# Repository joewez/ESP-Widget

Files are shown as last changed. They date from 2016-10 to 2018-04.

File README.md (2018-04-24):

# ESP Widget

The "widget" is a device based on a Wemos D1 Mini (ESP8266).  It consists of...

    - A Wemos D1 Mini WiFi Microcontroller Board
    - A SSD1306 128x64 OLED Display (White)
    - A single WS2812/Neopixel Color LED
    - A small piezo-electric buzzer
    - Three (3) tactile input buttons

It uses MicroPython to control Wifi setup and operation of the device.

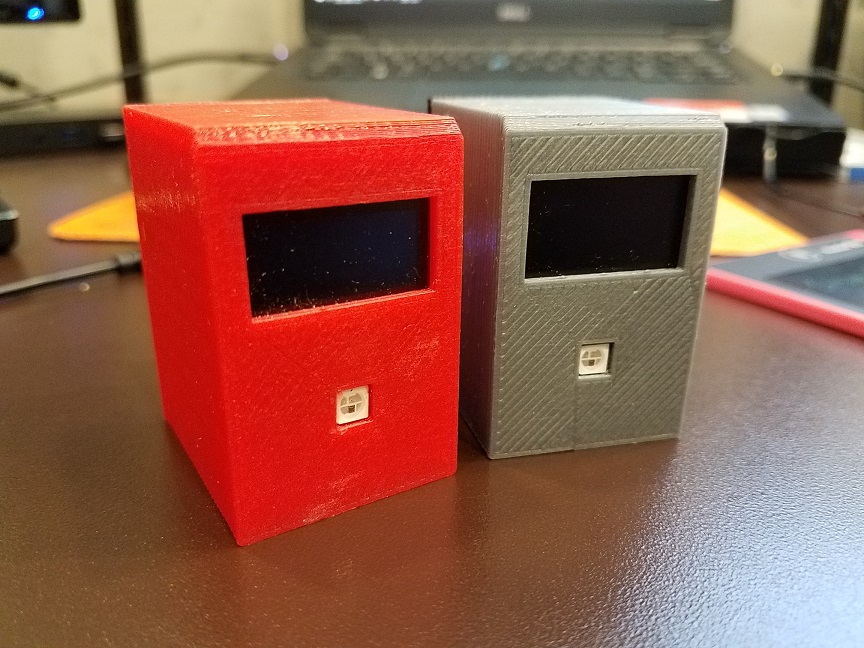
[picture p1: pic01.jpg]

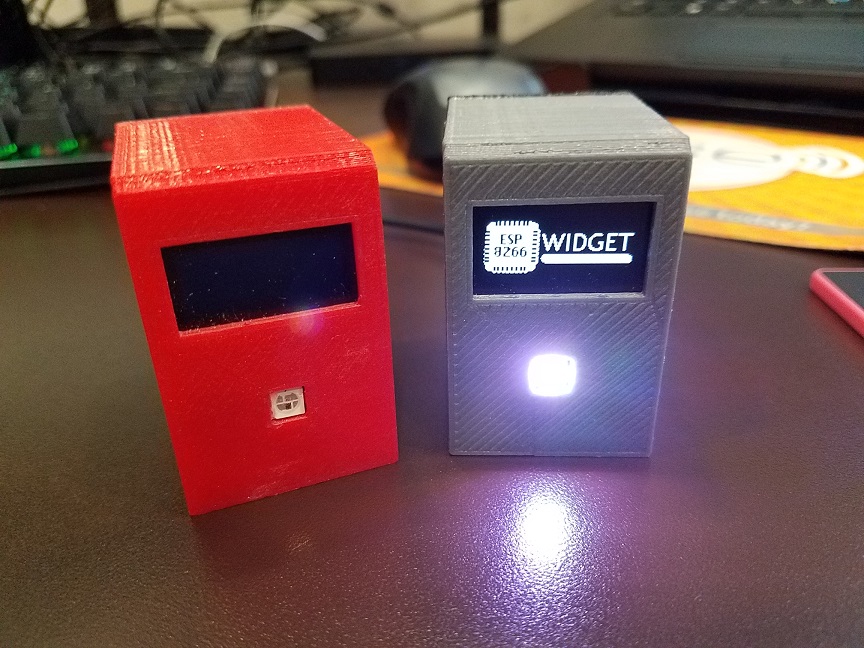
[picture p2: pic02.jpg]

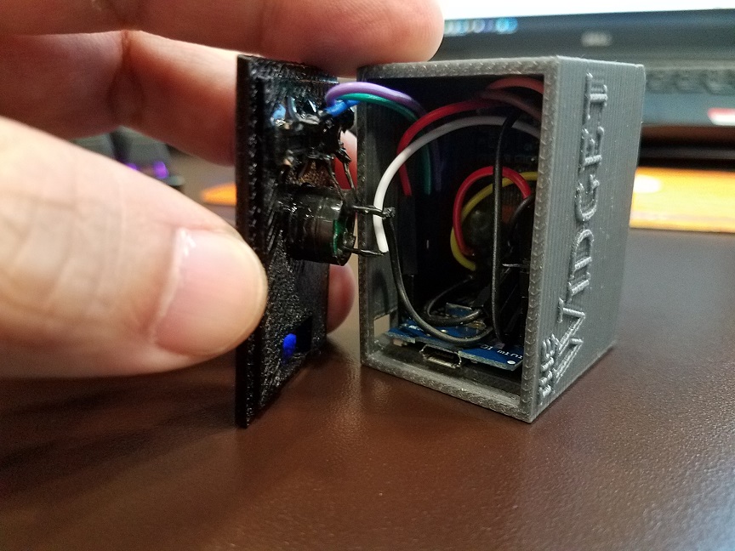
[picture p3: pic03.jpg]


The purpose of the device is to read a constantly updating document from the network and execute
the commands contained within.  The command allow you to...

    - Display text on the OLED
    - Change the color of the neopixel
    - Play a tone
    - etc...

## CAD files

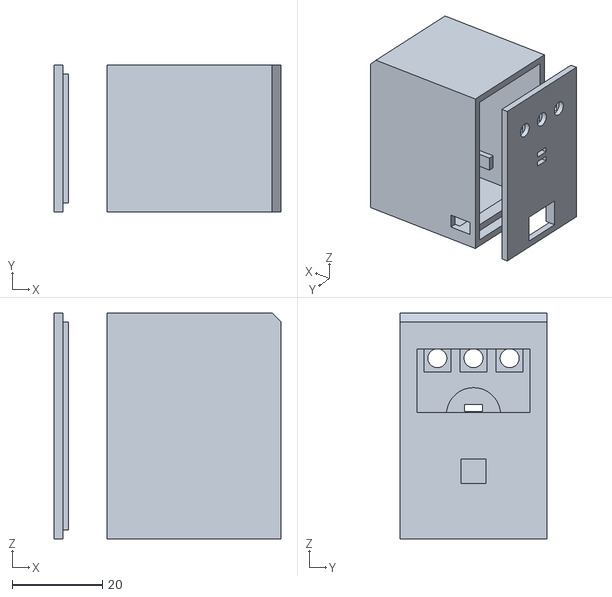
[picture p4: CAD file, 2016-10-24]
ESP Widget Case.stl
50.2 x 32.5 x 50.0

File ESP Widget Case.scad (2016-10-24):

/* [Height] */

// Final height of the stack walls.
height = 50.0;

// ---------------------------------------------------------------------------------------------------------
// do not need to modify anything below here
// ---------------------------------------------------------------------------------------------------------
/* [Hidden] */

thickness = 2.0;
fudge = 0.1;

width = 38.5;
depth = 32.50;
 
cavity_width = width - thickness;
cavity_depth = depth - (2 * thickness);
cavity_height = height - (2 * thickness);

hole_diameter = 7.0;

slit_width = 4.0;
slit_height = 23.0;

// lid
rotate([0, 0, 180])
difference() {   
    union() {
        translate([30, 0, height / 2.0]) cube([2, depth, height], center = true);
        translate([28.5, 0, height / 2.0]) cube([1.5, cavity_depth, cavity_height], center = true);
    }
    translate([27, -6, 2]) cube([5, 12, 8]);
    
    translate([29, 0, 29]) rotate([0, 90, 0]) cube([1.5, 4, 5], center = true);
    translate([29, 0, 26]) rotate([0, 90, 0]) cube([1.5, 4, 5], center = true);

    translate([30, 8, 40]) rotate([0, 90, 0]) cylinder(h = 5, r1 = 2.1, r2 = 2.1, $fn=36, center = true);
    translate([28.5, 8, 40]) rotate([0, 0, 0]) cube([2, 6, 6], center = true);
    translate([30, 0, 40]) rotate([0, 90, 0]) cylinder(h = 5, r1 = 2.1, r2 = 2.1, $fn=36, center = true);
    translate([28.5, 0, 40]) rotate([0, 0, 0]) cube([2, 6, 6], center = true);
    translate([30, -8, 40]) rotate([0, 90, 0]) cylinder(h = 5, r1 = 2.1, r2 = 2.1, $fn=36, center = true);
    translate([28.5, -8, 40]) rotate([0, 0, 0]) cube([2, 6, 6], center = true);

    translate([26.5, 0, 27.5]) rotate([0, 90, 0]) cylinder(h = 5, r1 = 6, r2 = 6, $fn=36, center = true);

}


// base

//rotate([0, 0, 180])
union() {
    translate([13.5, -(cavity_depth / 2.0), 2]) cube([4.0, cavity_depth, 4.0]);
    translate([-16, -(cavity_depth / 2.0), 2]) cube([4.0, cavity_depth, 2.0]);    
    translate([-2, 12.5, 7]) cube([20.0, 2, 4.0]);    
    translate([-2, -14.5, 7]) cube([20.0, 2, 4.0]);    
    difference () {
        translate([0, 0, height / 2.0]) cube([width, depth, height], center = true); 
        translate([-1, 0, (cavity_height / 2.0) + thickness]) cube([cavity_width + fudge, cavity_depth, cavity_height], center = true);
        translate([-17.25, 13.0, 4]) cube([7, 5, 4]);         
        translate([22, 0, 72.5]) rotate([0, -45,0]) cube([width, depth + 2, 31], center = true);

        translate([18, 0, 15]) rotate([0, 90, 0]) cube([5.5,5.5,5.5], center = true);
        translate([18, 0, 35]) rotate([0, 90, 0]) cube([14, 25,3], center = true);

        translate([17.5, 4, 15]) rotate([0, 90, 0]) cube([2,2,2], center = true);
        translate([17.5, -4, 15]) rotate([0, 90, 0]) cube([2,2,2], center = true);
        
        translate([-18, 0, 29]) rotate([0, 90, 0]) cube([1.5, 4, 3], center = true);
        translate([-18, 0, 26]) rotate([0, 90, 0]) cube([1.5, 4, 3], center = true);
        
        translate([-18, 10, 40]) rotate([0, 90, 0]) cylinder(h = 3, r1 = 2.1, r2 = 2.1, $fn=36, center = true);
        translate([-18, 0, 40]) rotate([0, 90, 0]) cylinder(h = 3, r1 = 2.1, r2 = 2.1, $fn=36, center = true);
        translate([-18, -10, 40]) rotate([0, 90, 0]) cylinder(h = 3, r1 = 2.1, r2 = 2.1, $fn=36, center = true);
        
    }    
        
}

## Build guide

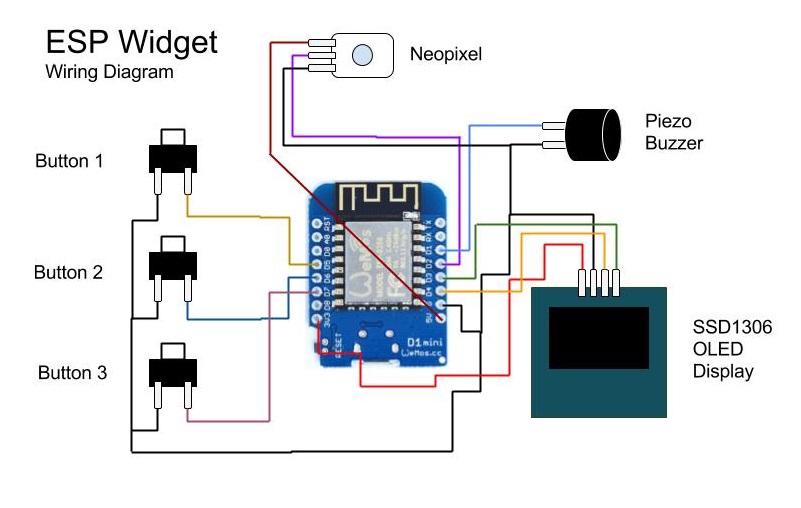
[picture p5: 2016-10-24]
ESP Widget Wiring.jpg

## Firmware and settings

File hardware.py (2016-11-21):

import machine
from machine import I2C, Pin
import ssd1306
import neopixel
import time

class Hardware:

    # Constructor initializes all the hardware objects

    def __init__(self):
        self.i2c = I2C(sda=Pin(0), scl=Pin(2))
        self.display = ssd1306.SSD1306_I2C(128, 64, self.i2c, 0x3c, False)
        self.np = neopixel.NeoPixel(machine.Pin(4), 1)
        self.button1 = machine.Pin(14, machine.Pin.IN, machine.Pin.PULL_UP)
        self.button2 = machine.Pin(12, machine.Pin.IN, machine.Pin.PULL_UP)
        self.button3 = machine.Pin(13, machine.Pin.IN, machine.Pin.PULL_UP)
        self.buzzer = machine.PWM(machine.Pin(5))

    # OLED display routines

    def oled_clear(self):
        self.display.fill(0)

    def oled_pixel(self, x, y, col):
        self.display.pixel(x, y, col)

    def oled_show(self):
        self.display.show()

    def oled_text(self, text, x = 0, y = 0):
        for xx in range(x, x + (len(text) * 8)):
            for yy in range(y, y + 8):
                self.display.pixel(xx, yy, 0)
        self.display.text(text, x, y)

    def hex2bits(self, hexstr):
        bitstr = ""
        for pos in range(0, len(hexstr) - 1, 2):
            newhex = hexstr[pos:pos + 2]
            newint = int(newhex, 16)
            newbin = bin(newint)[2:]
            newbits = '0' * (8 - len(newbin)) + newbin
            bitstr += newbits
        return bitstr

    def oled_graphic(self, file, origin_x = 0, origin_y = 0):
        pic = [line.rstrip('\r\n') for line in open(file)]
        for y, row in enumerate(pic):
            line = self.hex2bits(row)
            for x, col in enumerate(line):            
                if col == "1":
                    self.display.pixel(origin_x + x, origin_y + y, 1)
                else:
                    self.display.pixel(origin_x + x, origin_y + y, 0)


    def oled_line(self, x1, y1, x2, y2, col=1):
        dx = x2 - x1
        dy = y2 - y1
     
        is_steep = abs(dy) > abs(dx)
        if is_steep:
            x1, y1 = y1, x1
            x2, y2 = y2, x2
     
        swapped = False
        if x1 > x2:
            x1, x2 = x2, x1
            y1, y2 = y2, y1
            swapped = True
     
        dx = x2 - x1
        dy = y2 - y1
     
        error = int(dx / 2.0)
        ystep = 1 if y1 < y2 else -1
     
        y = y1
        points = []
        for x in range(x1, x2 + 1):
            coord = (y, x) if is_steep else (x, y)
            points.append(coord)
            error -= abs(dy)
            if error < 0:
                y += ystep
                error += dx
     
        if swapped:
            points.reverse()

        for point in points:
            self.display.pixel(point[0], point[1], col)

    def oled_circle(self, x0, y0, radius, col=1):
        x = radius
        y = 0
        err = 0

        while x >= y:
            self.display.pixel(x0 + x, y0 + y, col)
            self.display.pixel(x0 + y, y0 + x, col)
            self.display.pixel(x0 - y, y0 + x, col)
            self.display.pixel(x0 - x, y0 + y, col)
            self.display.pixel(x0 - x, y0 - y, col)
            self.display.pixel(x0 - y, y0 - x, col)
            self.display.pixel(x0 + y, y0 - x, col)
            self.display.pixel(x0 + x, y0 - y, col)

            y += 1
            err += 1 + 2*y
            if 2*(err-x) + 1 > 0:
                x -= 1
                err += 1 - 2*x    

    def oled_box(self, x1, y1, x2, y2, col=1):
        for x in range(x1, x2):
            self.display.pixel(x, y1, col)
            self.display.pixel(x, y2, col)
        for y in range(y1, y2):
            self.display.pixel(x1, y, col)
            self.display.pixel(x2, y, col)
            
    def oled_block(self, x1, y1, x2, y2, col=1):
        for x in range(x1, x2):
            for y in range(y1, y2):
                self.display.pixel(x, y, col)

    # NeoPixel control

    def pixel_color(self, red, green, blue):
        self.np[0] = (red, green, blue)
        self.np.write()
        time.sleep_ms(50)
        self.np[0] = (red, green, blue)
        self.np.write()

    # Input buttons

    def button_pressed(self, pin):
        if pin.value() == 0:
            active = 0
            while pin.value() == 0 and active < 75:
                active += 1
                time.sleep_ms(1)
            if pin.value() == 0 and active >= 75:
                self.buzzer_play(1000, 128, 50)
                return True
            else:
                return False
        else:
            return False
        
    def button1_pressed(self):
        return self.button_pressed(self.button1)

    def button2_pressed(self):
        return self.button_pressed(self.button2)

    def button3_pressed(self):
        return self.button_pressed(self.button3)

    # Piezo speaker

    def buzzer_play(self, freq, duty, duration):
        self.buzzer.freq(freq)
        self.buzzer.duty(duty)
        time.sleep_ms(duration)
        self.buzzer.deinit()

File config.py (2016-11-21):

import network
import socket
import ure
import time
import gc

sta = network.WLAN(network.STA_IF)
ap = network.WLAN(network.AP_IF)

# ------------------------------------------------------
# helper routines for doConfigWork()
# ------------------------------------------------------

def send_response(client, payload, status_code=200):
    client.sendall("HTTP/1.0 {} OK\r\n".format(status_code))
    client.sendall("Content-Type: text/html\r\n")
    client.sendall("Content-Length: {}\r\n".format(len(payload)))
    client.sendall("\r\n")
    
    if len(payload) > 0:
        client.sendall(payload)

# --------------------------------------------------------

def handle_root(client):
    response_header = """
        <h1>ESPWidget Wi-Fi Setup</h1>
        <form action="configure" method="post">
          <label for="ssid">SSID</label>
          <select name="ssid" id="ssid">
    """
    
    response_variable = ""
    turned_on = False
    if not sta.active():
        sta.active(True)
        turned_on = True
    for ssid, *_ in sta.scan():
        response_variable += '<option value="{0}">{0}</option>'.format(ssid.decode("utf-8"))
    if turned_on:
        sta.active(False)

    response_footer = """
           </select> <br/>
           Password: <input name="password" type="password"></input> <br />
           <input type="submit" value="Submit">
         </form>
    """
    send_response(client, response_header + response_variable + response_footer)

# --------------------------------------------------------

def handle_configure(client, request):
    match = ure.search("ssid=([^&]*)&password=(.*)", request)
    
    if match is None:
        send_response(client, "Parameters not found", status_code=400)
        return
    
    ssid = match.group(1)
    password = match.group(2)
    
    if len(ssid) == 0:
        send_response(client, "SSID must be provided", status_code=400)
        return
    
    sta.active(True)
    sta.connect(ssid, password)
    
    send_response(client, "Wi-Fi configured for SSID {}<br />Your widget should now connect...".format(ssid))
    return

# --------------------------------------------------------

def handle_not_found(client, url):
    send_response(client, "Path not found: {}".format(url), status_code=404)

# ------------------------------------------------------------------
# will run the AP and the web server to get the SSID and password
# ------------------------------------------------------------------

def Work(hw):

    hw.pixel_color(64, 0, 0)

    sta.active(False)
    ap.active(True)
    ap.config(essid="ESPWidget", password="thereisnospoon")

    server_socket = socket.socket()
    addr = socket.getaddrinfo("0.0.0.0", 80)[0][-1]
    server_socket.setsockopt(socket.SOL_SOCKET, socket.SO_REUSEADDR, 1)
    server_socket.bind(addr)
    server_socket.listen(1)

    hw.oled_clear()
    hw.oled_text("Connect to...", 0, 0)
    hw.oled_text("ESPWidget", 16, 12)
    hw.oled_text("Browse to...", 0, 24)
    hw.oled_text("192.168.4.1", 16, 36)
    hw.oled_show()

    while True:
        client, addr = server_socket.accept()
        client.settimeout(5.0)
        
        request = b""
        try:
            while not "\r\n\r\n" in request:
                request += client.recv(512)
        except OSError:
            pass
        
        if "HTTP" not in request:
            client.close()
            continue
        
        url = ure.search("(?:GET|POST) /(.*?)(?:\\?.*?)? HTTP", request).group(1).rstrip("/")

        finished = False
        if url == "":
            handle_root(client)
        elif url == "configure":
            handle_configure(client, request)
            finished = True
        else:
            handle_not_found(client, url)
        
        client.close()

        if finished:
            hw.oled_clear()
            hw.oled_text("Connecting...", 0, 0)
            hw.oled_show()
            break

    server_socket.close()

    server_socket = None
    client = None
    addr = None
    request = None
    url = None
    finished = None
    gc.collect()

    import machine
    machine.reset()
    

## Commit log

2016-10-24 Imbedded Line and Circle and removed SPI class
2016-10-24 Merged into display driver
2016-10-24 Wiring diagram.
2016-10-24 3D printed case
    [ESP Widget Case.scad, ESP Widget Case.stl]
